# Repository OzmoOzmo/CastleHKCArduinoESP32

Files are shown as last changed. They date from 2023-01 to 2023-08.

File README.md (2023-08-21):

# CastleHKCArduinoESP32
=================================

Any questions I can be found via: https://www.boards.ie/discussion/2057113381

This is a HKC / SecureWatch Alarm compatible Remote Keypad that makes the Alarms functions and menus
accessible via any desktop or modern mobile phone browser.

It does this by emulating a real keypad - and making a virtual keypad available to your phone.

Features a WIFI connection to your router, Built in Webserver to present the virtual keypad - websockets to provide two way connection from your phone. Sends Email when an alarm is triggered. Also has an optional OLED screen you can add.

Tested on HKC SW8/12 - but should work on many of the older HKC models.

animation demo

Allows you to remote arm/disarm the panel as well as view logs and enter Engineer Menu etc.

Connection to the Alarm Panel requires connecting an ESP32 to the panels standard 3 wire Remote Keypad bus using the circuit described.

To compile use Platformio. Its possible to compile using Arduino IDE as well.

The circuit required is as follows.

It can be soldered up to your requirments and parts available - I used an Adafruit Proto Shield clone mounted on an ESP D1 R32 board.
Both available online from amazon/aliexpress and other sources for as low as $5 each.

Note: I have added a 10uF capacitor between GND and Reset on the ESP32 - this is a common fix to make it more reliable to flash new software to the ESP.

Circuit on a shield:  

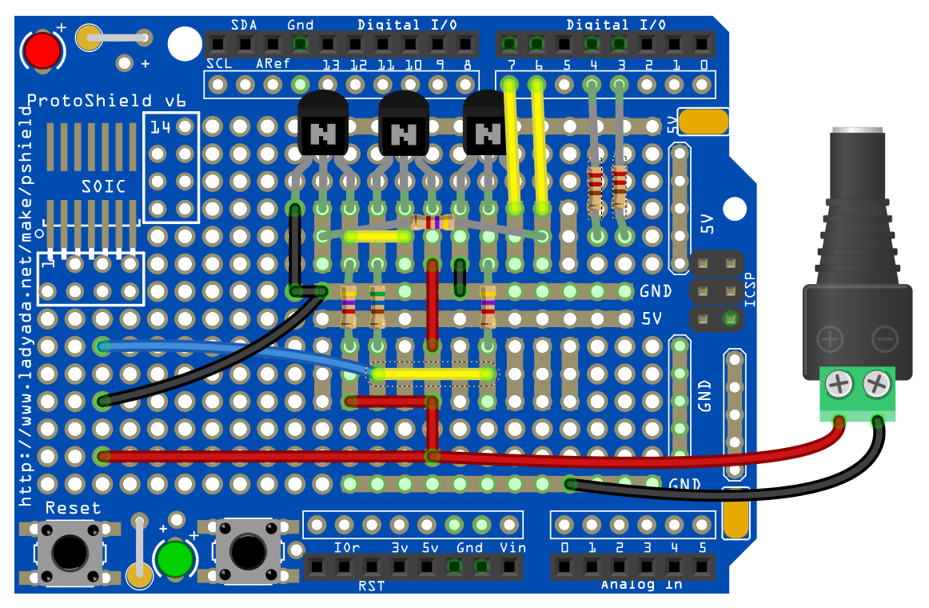
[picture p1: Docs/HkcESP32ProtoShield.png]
Circuit as shield

BLACK - goes to Panel GND  
BLUE - goes to RKP data  
RED - goes to Panels +12V  
Power Plug - Connect the shield over the ESP32 and Connect the power plug shown on the right to the ESP32 board.  

Or - on a breadboard:

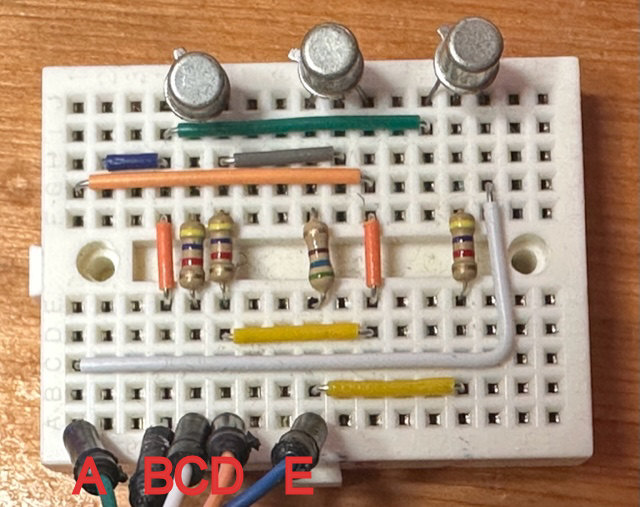
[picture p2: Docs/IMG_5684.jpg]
Circuit

A goes to ESP32 Receive (Esp Pin 16)  
B goes to Panel RKP GND and also ESp32 GND  
C goes to ESP32 Transmit (Esp Pin 27)  
D goes to Panels RKP port +12V  
E goes to Panels RKP data  
  
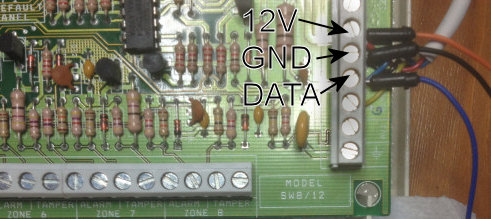
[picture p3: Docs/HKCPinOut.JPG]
HKC Connection


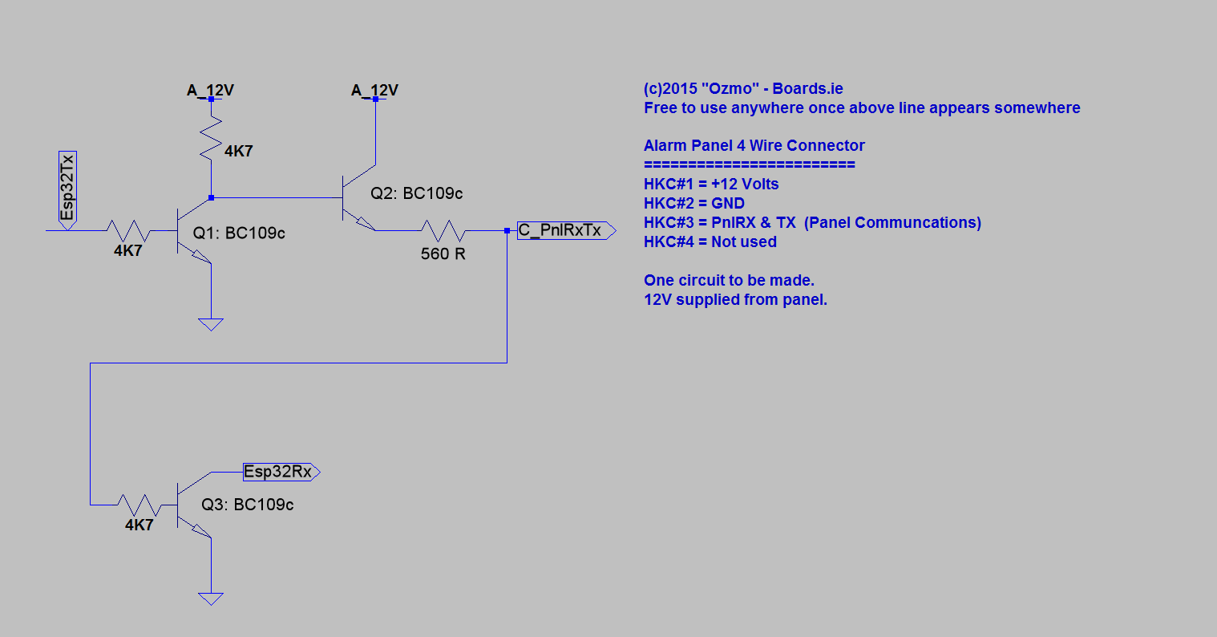
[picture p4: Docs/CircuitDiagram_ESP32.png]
Wiring Diagram


*Note: This is the latest code for an ESP32 - supporting Wifi, Chrome, most phones and Gmail - An easier to make, but less capable, Arduino UNO version using an Ethernet Shield is also available on my other GitHub repositories*
Feb 2023

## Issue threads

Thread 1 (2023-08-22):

Raspberry Pi Pico W

jorgechacblogspot, 2023-08-22:
https://github.com/earlephilhower/arduino-pico/issues/1433#issuecomment-1546783109%22)%60

"I hack/fixed the issue for myself by including these missing? files from Pico SDK 1.5 in my src folder... Im not sure if there is other code or libs missing - but this allows the above to compile and run and print to Terminal from the pico.

files: stdio_uart.h, stdio_usb.h, stdio.c, stdio_uart.c, stdio_usb.c, stdlib.c"

Hello OzmoOzmo, (sorry for asking here but there is no contact email in your github profile), to which specific paths should these files be copied?

OzmoOzmo, 2023-09-07:
I put the c files (stdio.c, stdio_uart.c, stdio_usb.c, stdlib.c) into the lib folder for each project I was working on eg.

\Blink\lib\uartcomms\src\

and the header files (stdio_uart.h, stdio_usb.h ) here:
\Blink\lib\uartcomms\src\pico

Works well then - I can use the official Pico sdk - which was needed for my projects.

My Platformio looks like this:

[env:pico]
platform = https://github.com/maxgerhardt/platform-raspberrypi.git
framework = arduino
board_build.core = earlephilhower
board_build.filesystem_size = 0.5m
board = pico
upload_protocol = cmsis-dap
debug_tool = cmsis-dap
monitor_speed = 115200
build_flags =
    -D PICO_STDIO_USB  ; not needed unless running without debugger
    -D PICO_STDIO_UART ; want real uart working as this is connected to picodebug
    ;-D DEBUG_RP2040_PORT=Serial

lib_deps = uartcomms ;*important* Ambroses library to fix print/uart issues
debug_speed = 5000

------sample c code:
#include <stdio.h>
#include "pico/stdlib.h"

#define LED_PIN 25
int main() {
    stdio_init_all();
    printf("Hello World...\n");
    gpio_init(LED_PIN);
    gpio_set_dir(LED_PIN, GPIO_OUT);
    while (true) {
         gpio_put(LED_PIN, 1);
         sleep_ms(25);
         gpio_put(LED_PIN, 0);
         sleep_ms(25);
    }
}

jorgechacblogspot, 2023-09-08:
OK thank you for answering.

Closed 2023-09-08.

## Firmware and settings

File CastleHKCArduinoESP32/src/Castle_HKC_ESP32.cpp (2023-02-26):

/*
*   Castle KeyPad
*
*   HKC Alarm Panel ESP32 Internet Enabled Keypad
*
*   For ESP32
*
*   See Circuit Diagram for wiring instructions
*
*   V1.04  March  2014: Arm Disarm Complete and tested as working
*   V1.2	  April  2014: Updated to use ABCD Keypad bus
*   V1.3	  April  2015: Updated to current Arduino IDE
*   V1.4	         2017: Various Updates for New Chrome Support
*   V2.0	         2023: Ported to ESP32
*
*   Author: Ozmo
*
*   See: http://www.boards.ie/vbulletin/showthread.php?p=88215184
*
*
*
*  Compile for ESP32 Dev Module 
*  For best results : Use on a "ESP32 D1 R32" - This has power converter built in so can power from Alarm Panel
*  
*  
*  It will compile within Arduino IDE with correct esp32 board libraries installed - but much easier using Platformio
*
*  ****See Config.h for all the configuration you may need*****
*/

#include "config.h"
#include "Log.h"
#include "RKP.h"
#include "SMTP.h"
#include "WebSocket.h"
#ifdef ENABLE_TELEGRAM
    #include "Telegram.h"
#endif

void ShowVersion(){
    #ifdef ESP32
    // Print chip information
    esp_chip_info_t chip_info;
    esp_chip_info(&chip_info);
    Serial.printf("ESP32 chip with %d CPU cores, WiFi%s%s, ",
            chip_info.cores,
            (chip_info.features & CHIP_FEATURE_BT) ? "/BT" : "",
            (chip_info.features & CHIP_FEATURE_BLE) ? "/BLE" : "");
    Serial.printf("ESP32 Model: %d, ", chip_info.model); //esp_chip_model_t (1 = ESP32)
    Serial.printf("silicon revision %d, ", chip_info.revision);
    Serial.printf("%dMB %s flash\n", spi_flash_get_chip_size() / (1024 * 1024),
            (chip_info.features & CHIP_FEATURE_EMB_FLASH) ? "embedded" : "external");

    Serial.printf("CPU Frequency: %d Mhz\n", getCpuFrequencyMhz()); //Get CPU clock
    #endif
    #ifdef ESP8266
    //todo: add useful diagnostics for 8266
    Serial.println("ESP8266");
    #endif
}

void setup()
{
    //--debug logging start
    Log_Init();

    LogLn("\r\n-----[Start]-----");
    ShowVersion();

    LogLn("LCD Display Init..");
    LCD_Init();

    #ifdef DEBUG_LOG
        LogLn("Logging On."); //Enable Silent Mode for full speed
    #else
        LogLn("(Mostly)Silent Mode enabled.");
    #endif

    LogLn("RKP Init..");
    RKPClass::Init();

    LogLn("Server Init..");
    WebSocket::ServerInit();

    LogLn("SMTP Init..");
    SMTP::QueueEmail(MSG_START); //Creates a bootup email
    
    SMTP::StartEmailMonitor();

    #ifdef ENABLE_TELEGRAM
    Telegram::StartMonitor();
    Telegram::QueueTelegram("Alarm Startup"); //Creates a bootup email
    #endif

    WebSocket::StartWebServerMonitor();

    //Flashing led on Pin 12 show us we are still working ok
    LogLn("If LED not Blinking - Ensure Panel is Connected.");
    pinMode(ledFeedback, OUTPUT);
    pinMode(LED_Stat, OUTPUT);
    pinMode(LED_BUILTIN, OUTPUT);
}

void loop()
{
    LogLn("Main Loop");

    while (true)
    {
        //check for comms activity
        //Poor performance for RKP when in a thread - we will poll on core0
        RKPClass::Poll();

        //Flash status led
        static int tiLast = 0;
        int tiNow = millis();
        if (tiLast < tiNow - 500){
            tiLast = tiNow;
            digitalWrite(ledFeedback, !digitalRead(ledFeedback));
            digitalWrite(LED_BUILTIN, !digitalRead(LED_BUILTIN));
        }
    }
}

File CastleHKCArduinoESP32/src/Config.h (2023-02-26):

/*
 * Config.h
 *
 *
 *   HKC Alarm Panel Arduino Internet Enabled Keypad
 *
 *   For Arduino (UNO or Leonardo) with added Ethernet Shield
 *
 *   See Circuit Diagram for wiring instructions
 *
 *   Author: Ozmo
 *
 *   See: http://www.boards.ie/vbulletin/showthread.php?p=88215184
 *
*/

//--------Configuration Start----------

#pragma once

//Wifi Password (Required)
#define WIFI_SSID "{WIFI NAME HERE}"
#define WIFI_PASSWORD "{WIFI PASS HERE}"


//Email Passwords - Works well with gmail
//(optional) comment out "#define SENDEMAILS" to not send emails
//Important: you must create a password this way: https://support.google.com/accounts/answer/185833
#define SMTP_SERVER "smtp.gmail.com"        
#define SMTP_USER "YourSendEmailAddress@gmail.com"
#define SMTP_PASS "GoogleGeneratedPasscode" //see comment above
#define EMAIL_ADDR "example@example.com"  //Email to send to
#define SMTP_PORT 465 //465 works ok for GMAIL
#define EMAIL_SUBJECT "House Alarm"

//LED_BUILTIN Builtin Red led is Pin 2 on D1 R32 (17 on some esp32)
// #define LED_Stat 17 // this binks when packets are sent to panel
// #define ledFeedback 25 // Blink a Led we can use to show ESP is running
// #define SERIAL1_TXACTIVE -1 //Pin is lit when sending
// //#Serial Port pins - We leave Serial0 for programming and debug - this serial port connects to the HKC Panel via the circuit
// //These are the Pins to use for Serial Connection
// #define SERIAL1_RXPIN 16
// #define SERIAL1_TXPIN 27

#define ledFeedback 25 // Blink a Led we can use to show ESP is running
#define LED_Stat 17 // this binks when packets are sent to panel
#define SERIAL1_RXPIN 16
#define SERIAL1_TXPIN 27
#define SERIAL1_TXACTIVE -1 //Pin is flashed when sending (not used)
//LCD Display Pins
//SDA=18, SCL=19 for my custom boards
//SDA=5,  SCL=4 for ESP board with built in screen (https://www.aliexpress.com/item/33047481007.html)
#define SCREEN_GND GND
#define SCREEN_3V  18
#define SCREEN_SCL 19
#define SCREEN_SDA 23

//The Arduino IP address and Port (192.168.1.177)
#define IP_ME "192.168.0.177"
#define IP_GW "192.168.0.1"
#define IP_SN "255.255.255.0"
#define IP_DNS IP_GW //This will use your ISP dns - if that doesnt work - try "8.8.8.8" (googles dns)

#define IP_P 80  //The IP Port for the http server


//Alexa Config
//a hex character 0..9 or a..f to force Alexa to see as new device hub 
// its cached by alexa - so increase by 1 if alexa not discovering this as a new device
#define DEVICEHUB_ID '0'
//End Alexa integration


/////////
//These are advanced configuration...

//Switches - Comment out to disable features.. 
//#define SENDEMAILS //Comment line out to disable sending emails (if email fails to send - wifi will reset!)
#define DEBUG_LOG //Comment out to disable all debug comments
#define ENABLE_DISPLAY //Comment out to disable using LCD
//#define ENABLE_TELEGRAM //Comment out to disable using TELEGRAM
//#define DUMP_RAW_LINE_DATA //This will dump all data from Arduino in hex to debug log (DEBUG_LOG required)
//#define DEBUG_SHOW_ALL_TX //This will dump all data sent from ESP to Alarm to terminal
//#define DEBUG_SHOW_ALL_RX //This will dump all data sent from Alarm to terminal

//#define DEBUG_SHOW_DISPLAY ///Only show LCD Display on terminal
//#define ALEXA //comment out to disable Alexa support (alexa support is under construction)
#define WIFI  //comment out for no wifi - not going to do a lot then
#define WEBSERVER

//Build Version (displayed on webpage)
#define sVersion "Castle V6.01"

//Maximum web browsers that can connect at a time
#define MAX_CLIENTS 16

//Symbols as displayed on the HTML page
#define KEY_STAR "&#9650;"  //unicode arrow up "*"
#define KEY_POUND "&#9660;" //unicode arrow down "#"


enum { WIFI_DOWN = 0, WIFI_PENDING = 1, WIFI_OK = 2 };


//Telegram Config
//Telegram BOT Token (Get from Botfather)
#define BOT_TOKEN "XXXXXXXXX:XXXXXXXXXXXXXXXXXXXXXXXXXXXXXXXXXXX"
//Telegram User - this is your user ID - only this user can interact with this app
#define CHAT_ID "XXXXXXXXXX"
const unsigned long BOT_MTBS = 3000; // mean time between scan messages

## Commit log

2023-01-01 Initial Checkin - HKC code ported to ESP32
2023-02-08 Esp32 HKC RKP
    [AritechESP32ProtoShield.fzz]
2023-02-12 LCD Display improvments and added Green,Red,Yellow LEDs in HTML.
    [AritechArduinoProtoShield.fzz]
2023-02-26 Added Telegram notifications, Display and Docs.
    [AritechArduinoProtoShield.fzz, AritechESP32ProtoShield.fzz, HkcESP32ProtoShield.fzz]
